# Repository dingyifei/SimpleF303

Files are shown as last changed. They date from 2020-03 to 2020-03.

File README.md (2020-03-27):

# SimpleF303
 A QFP-48 STM32F303 minimum board design

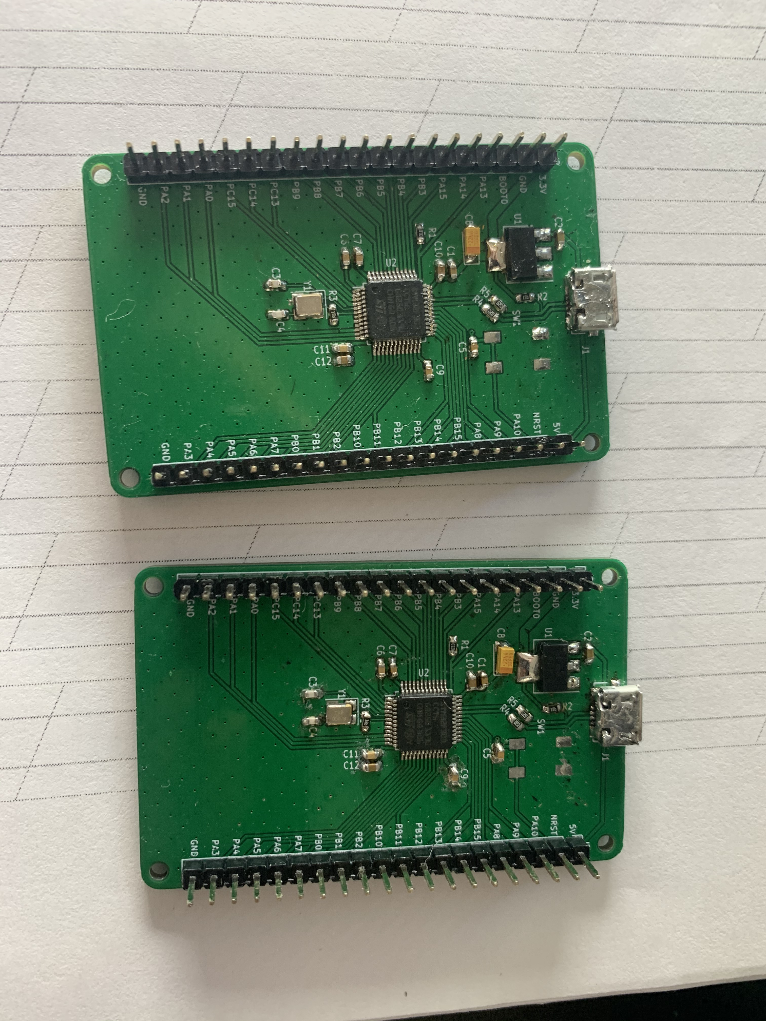
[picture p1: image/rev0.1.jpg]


## Features:

1. It is functional
2. u can replace the LDO with a more powerful one
3. hand solder
4. Simple?

## Known Issues:

- it doesn't have LED indicator 
- you need to pull BOOT0 to 3.3v before pulling the NRST pin in order to enter DFU
- Uncommon reset button footprint (you can easily replace it )
- Maybe impossible to power it without USB
- hard to solder SMD crystal (you can easily replace it )

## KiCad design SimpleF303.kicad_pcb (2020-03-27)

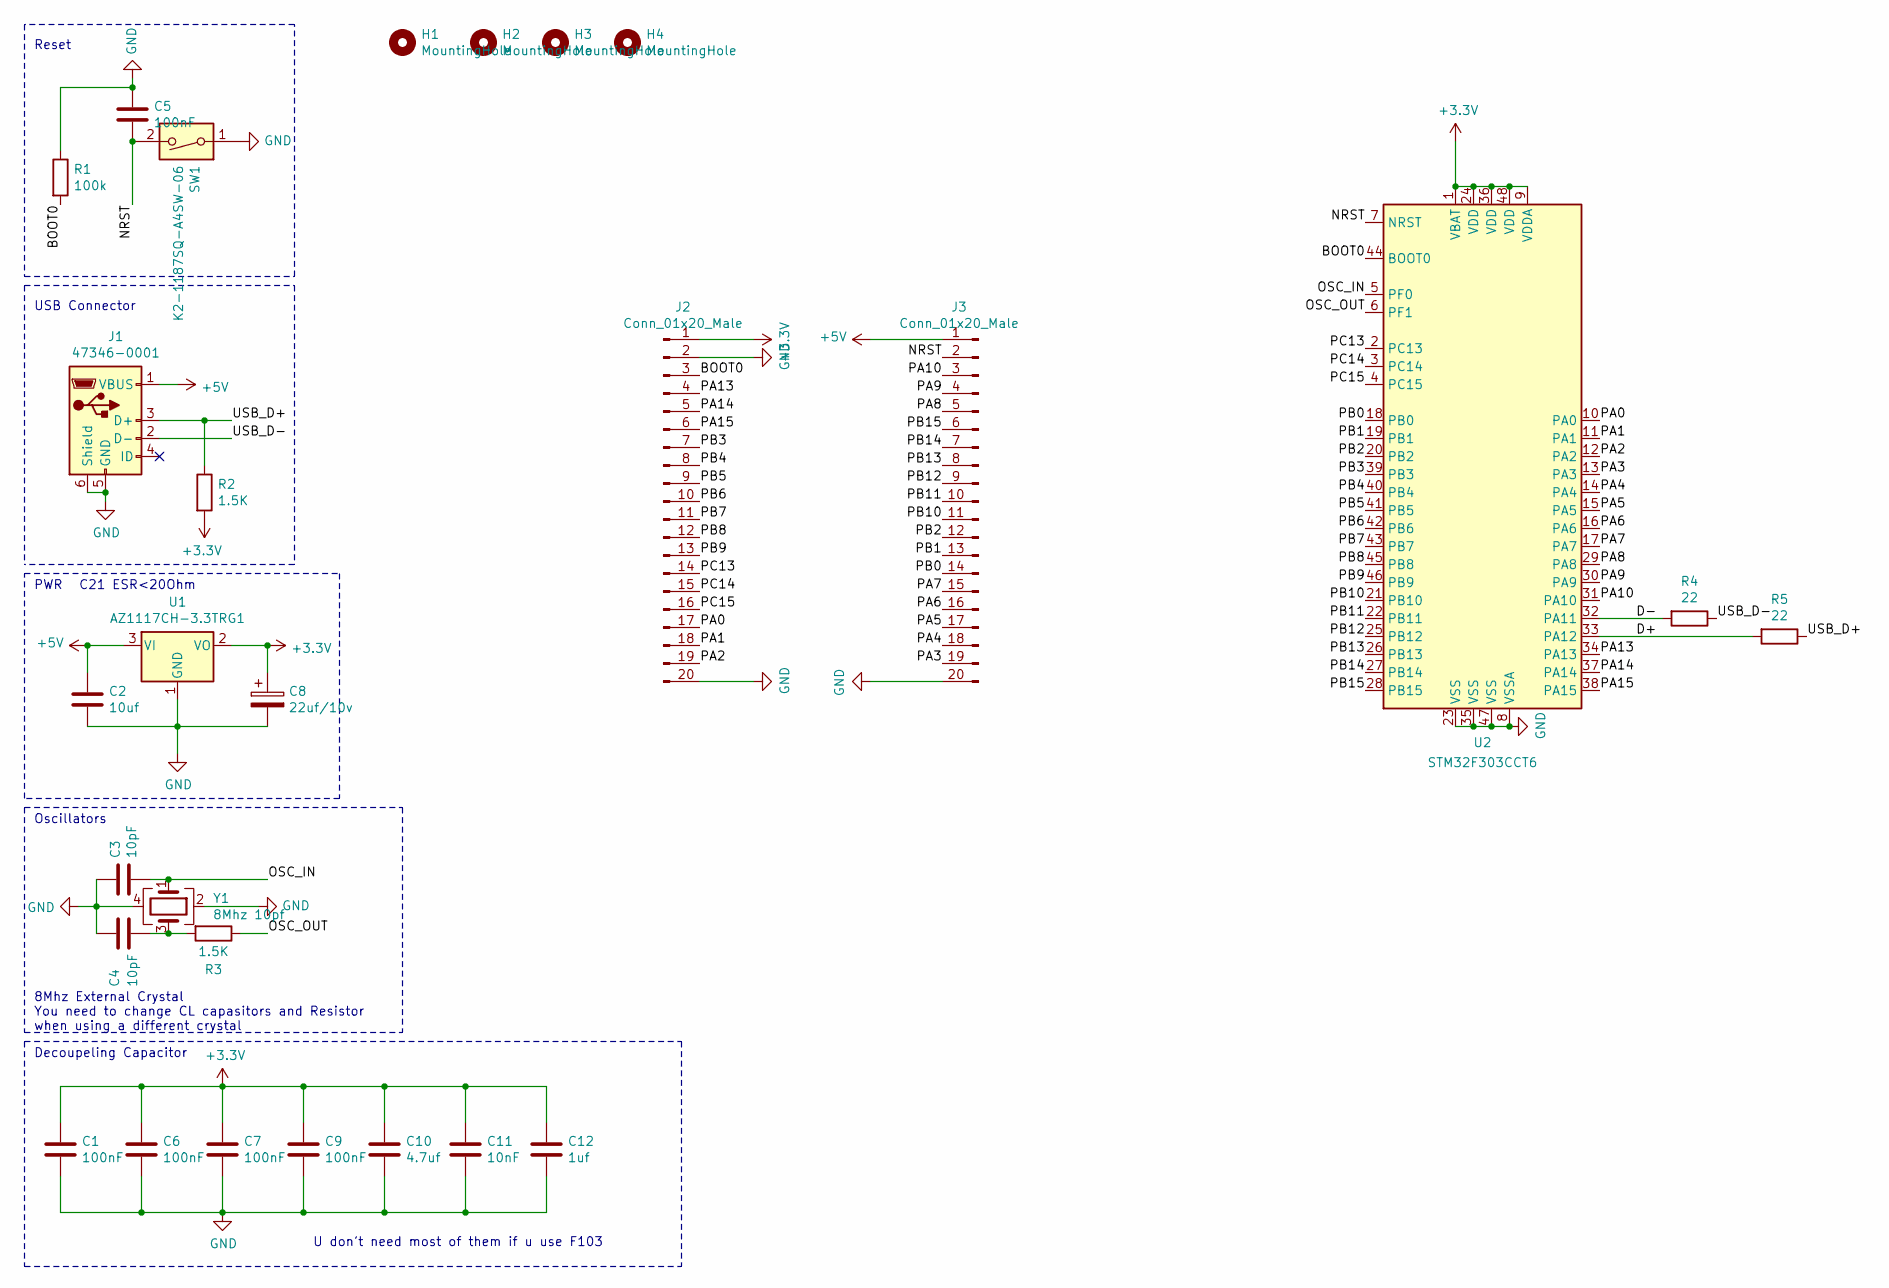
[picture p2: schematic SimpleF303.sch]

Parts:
C1, C5, C6, C7, C9: 100nF; C_0603_1608Metric; Part Number 0603B104K160CT; LCSC C80516
C2: 10uf; C_0603_1608Metric; Part Number 0603X106K100NT; LCSC C38898
C3, C4: 10pF; C_0603_1608Metric; Part Number CC0603GRNPO9BN100; LCSC C325468
C8: 22uf/10v; CP_EIA-3216-18_Kemet-A; Part Number TAJA226K010RNJ; LCSC C11366
C10: 4.7uf; C_0603_1608Metric; Part Number CL10A475KA8NQNC; LCSC C69335
C11: 10nF; C_0603_1608Metric; Part Number CL10B103JB8NNNC; LCSC C7248
C12: 1uf; C_0603_1608Metric; Part Number UMK107AB7105KA-T; LCSC C105174
H1, H2, H3, H4: MountingHole; MountingHole_2.1mm
J1: 47346-0001; USB_Micro-B_Molex_47346-0001; Part Number 47346-0001; LCSC C132560
J2, J3: Conn_01x20_Male; PinHeader_1x20_P2.54mm_Vertical; Part Number 2.54mm 1x40P; LCSC C2337
R1: 100k; R_0603_1608Metric; Part Number CR0603FA1003G; LCSC C100703
R2, R3: 1.5K; R_0603_1608Metric; Part Number RTT031501FTP; LCSC C103303
R4, R5: 22; R_0603_1608Metric; Part Number CR0603FA22R0G; LCSC C100876
SW1: K2-1187SQ-A4SW-06; Part Number K2-1187SQ-A4SW-06; LCSC C92584
U1: AZ1117CH-3.3TRG1; SOT-223-3_TabPin2; Part Number AZ1117CH-3.3TRG1; LCSC C92102
U2: STM32F303CCT6; LQFP-48_7x7mm_P0.5mm; Part Number STM32F303CCT6; LCSC C81523
Y1: 8Mhz 10pf; Crystal_SMD_3225-4Pin_3.2x2.5mm; Part Number TAXM8M4RDBCCT2T; LCSC C400090

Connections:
+3V3: C1.1, C6.1, C7.1, C8.1, C9.1, C10.1, C11.1, C12.1, J2.1, R2.2, U1.2 (VO), U2.1 (VBAT), U2.9 (VDDA), U2.24 (VDD), U2.36 (VDD), U2.48 (VDD)
+5V: C2.1, J1.1 (VBUS), J3.1, U1.3 (VI)
/BOOT0: J2.3, R1.2, U2.44 (BOOT0)
/D+: R5.2, U2.33 (PA12)
/D-: R4.2, U2.32 (PA11)
/NRST: C5.2, J3.2, SW1.2, U2.7 (NRST)
/OSC_IN: C3.2, U2.5 (PF0), Y1.1
/OSC_OUT: R3.1, U2.6 (PF1)
/PA0: J2.17, U2.10 (PA0)
/PA1: J2.18, U2.11 (PA1)
/PA2: J2.19, U2.12 (PA2)
/PA3: J3.19, U2.13 (PA3)
/PA4: J3.18, U2.14 (PA4)
/PA5: J3.17, U2.15 (PA5)
/PA6: J3.16, U2.16 (PA6)
/PA7: J3.15, U2.17 (PA7)
/PA8: J3.5, U2.29 (PA8)
/PA9: J3.4, U2.30 (PA9)
/PA10: J3.3, U2.31 (PA10)
/PA13: J2.4, U2.34 (PA13)
/PA14: J2.5, U2.37 (PA14)
/PA15: J2.6, U2.38 (PA15)
/PB0: J3.14, U2.18 (PB0)
/PB1: J3.13, U2.19 (PB1)
/PB2: J3.12, U2.20 (PB2)
/PB3: J2.7, U2.39 (PB3)
/PB4: J2.8, U2.40 (PB4)
/PB5: J2.9, U2.41 (PB5)
/PB6: J2.10, U2.42 (PB6)
/PB7: J2.11, U2.43 (PB7)
/PB8: J2.12, U2.45 (PB8)
/PB9: J2.13, U2.46 (PB9)
/PB10: J3.11, U2.21 (PB10)
/PB11: J3.10, U2.22 (PB11)
/PB12: J3.9, U2.25 (PB12)
/PB13: J3.8, U2.26 (PB13)
/PB14: J3.7, U2.27 (PB14)
/PB15: J3.6, U2.28 (PB15)
/PC13: J2.14, U2.2 (PC13)
/PC14: J2.15, U2.3 (PC14)
/PC15: J2.16, U2.4 (PC15)
/USB_D+: J1.3 (D+), R2.1, R5.1
/USB_D-: J1.2 (D-), R4.1
GND: C1.2, C2.2, C3.1, C4.1, C5.1, C6.2, C7.2, C8.2, C9.2, C10.2, C11.2, C12.2, J1.5 (GND), J1.6 (Shield), J2.2, J2.20, J3.20, R1.1, SW1.1, U1.1 (GND), U2.8 (VSSA), U2.23 (VSS), U2.35 (VSS), U2.47 (VSS), Y1.2, Y1.4
unnamed: C4.2, R3.2, Y1.3

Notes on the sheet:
PWR
C21 ESR<20Ohm
8Mhz External Crystal You need to change CL capasitors and Resistor when using a different crystal
USB Connector
Oscillators
Decoupeling Capacitor
Reset
U don't need most of them if u use F103

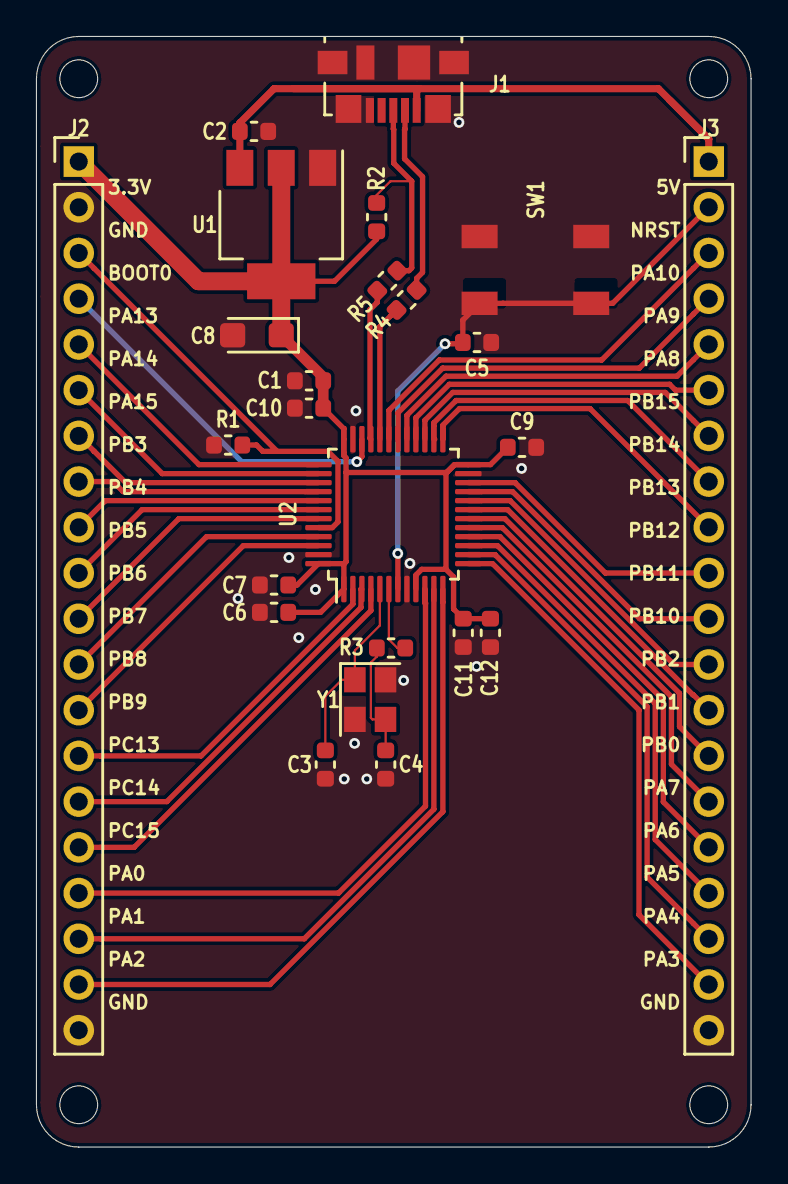
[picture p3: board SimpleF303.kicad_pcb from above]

Board: 2 copper layers, 39.7 x 61.7 mm, 28 parts (0 on the bottom side), 45 nets.

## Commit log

2020-02-15 I think it will work
    [SimpleF303-B_Cu.gbl, SimpleF303-B_Mask.gbs, SimpleF303-B_Paste.gbp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]
2020-02-17 clearly I can't get some parts so I change selection
    [SimpleF303-B_Cu.gbl, SimpleF303-B_Mask.gbs, SimpleF303-B_Paste.gbp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]
2020-02-20 small changes
    [SimpleF303-B_Cu.gbl, SimpleF303-B_Mask.gbs, SimpleF303-B_Paste.gbp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]
2020-02-21 Appearently buy parts is hard
    [SimpleF303-B_Cu.gbl, SimpleF303-B_Mask.gbs, SimpleF303-B_Paste.gbp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]
2020-03-27 update pcb, add BOM, edit readme
    [SimpleF303.kicad_pcb]

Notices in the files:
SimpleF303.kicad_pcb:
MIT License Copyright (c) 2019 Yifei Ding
